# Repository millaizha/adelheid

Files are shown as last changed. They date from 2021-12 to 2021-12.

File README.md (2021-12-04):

# 𝕬𝖉𝖊𝖑𝖍𝖊𝖎𝖉

The Adelheid is a 75% Alice-like keyboard.  
It's a fork of FateNozomi's Arisu files: [Arisu PCB](https://github.com/FateNozomi/arisu-pcb) &amp; [Arisu case](https://github.com/FateNozomi/arisu-case)

This repo is a hand-wired version forked from [floookay's Adelheid](https://github.com/floookay/adelheid) with some changes.

This repository includes files for:

- a layered case &rarr; [README.md](./case/README.md)

## Changes in this fork

Here is a list of things I added in this fork in comparison to the original Adelheid:

- [x] replaced page up with a rotary encoder
- [x] lowered home, end, and page up keys (will change into media keys)
- [x] added win and right control keys
- [x] used pro micro as the controller
- [x] changed thickness of some acrylics

## Layout

A spaced 75% layout on top of the Alice/Arisu-layout.

[Keyboard-Layout-Editor](http://www.keyboard-layout-editor.com/#/gists/3d5f924367b3b31ac1beb2d660264759)
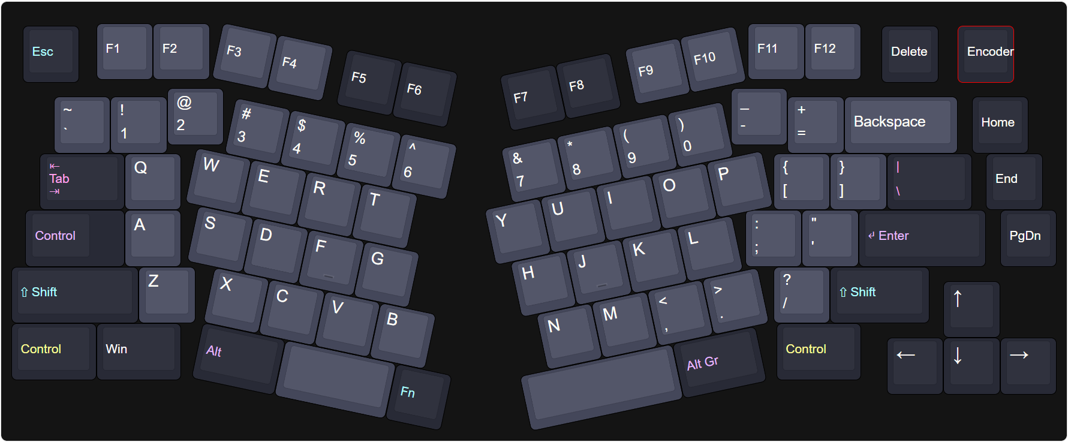
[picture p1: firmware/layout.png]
layout
 

## Firmware

See [firmware](https://github.com/millaizha/adelheid-hand-wire/tree/master/firmware)

## Images

For more images see [images.md](./IMAGES.md).

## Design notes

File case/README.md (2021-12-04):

# 𝕬𝖉𝖊𝖑𝖍𝖊𝖎𝖉 - Case

## Lasercutable Layered Case

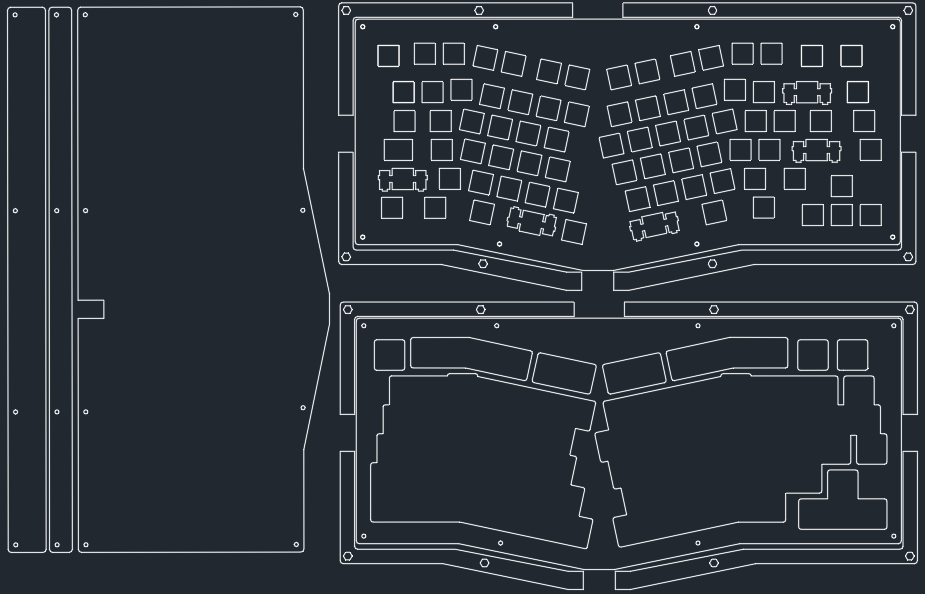
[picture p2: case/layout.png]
layout


final product (acrylic) to be put

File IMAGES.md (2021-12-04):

# 𝕬𝖉𝖊𝖑𝖍𝖊𝖎𝖉 hand-wired - Images

## Finished Keyboard

to be finished

## Case

CAD layout

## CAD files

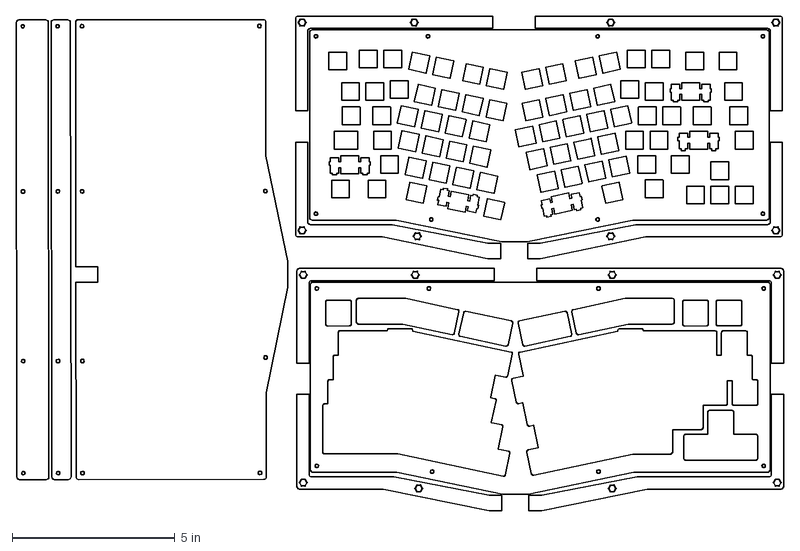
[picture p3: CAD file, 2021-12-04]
case/case.dxf
23.6 x 15.2 in

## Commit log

2020-04-16 added gerber files
    [adelheid-B_Cu.gbl, adelheid-B_Mask.gbs, adelheid-B_SilkS.gbo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]
2020-04-16 updated case files
    [adelheid_hipro_addon.dxf, adelheid_lopro.dxf, lasercut_adelheid_hipro_600x600.dxf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]
2020-04-27 added images of PCB and acrylic case layers
2020-04-27 updated pcb labels to be more consistent [v1.0.1]
    [adelheid-B_Cu.gbl, adelheid-B_Mask.gbs, adelheid-B_SilkS.gbo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]
2020-05-18 added footprints
    [arisu.kicad_pcb, arisu.sch, backlight.xlsx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]
2020-05-18 added column and row routing
    [arisu.kicad_pcb, matrix.sch]
2020-05-18 added matrix routing
    [arisu.kicad_pcb]
2020-05-18 finished pcb v2
    [arisu.kicad_pcb, arisu.sch, matrix.sch]
2020-05-18 restructured folder structure
    [adelheid.kicad_pcb, adelheid.sch, arisu.kicad_pcb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]
2020-05-20 updated readme + preparation for merge
    [adelheid-B_Cu.gbl, adelheid-B_Mask.gbs, adelheid-B_SilkS.gbo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]
2020-05-25 restructured case files, updated readmes
    [hipro_layers_addon.dxf, hipro_layers_addon.f3d, lopro_layers.dxf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]
2020-05-25 updated pcb readme
    [backlight.ods, backlight.xlsx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]
2020-05-27 made usb port cutout slightly larger
    [lopro_layers.dxf, lopro_layers.f3d]
2020-05-28 fixed revision number [Rev1.0]
    [adelheid.kicad_pcb, adelheid.sch]
2020-05-28 made usb port cutout larger in 600x600mm sheets
    [z_hipro_layers_600x600.dxf]
2020-06-01 altered hipro function row cutouts slightly
    these were slightly larger on the left half and have been resized so
    the cutouts should be more symmetrical now
    [hipro_layers_addon.dxf, hipro_layers_addon.f3d, z_hipro_layers_600x600.dxf]
2020-06-11 made pcb file compatible with stable KiCAD release
    compatible with KiCAD >5.1.6
    Previously pcbnew was only working with a testing build of KiCAD.
    [adelheid.kicad_pcb]
2020-07-11 switched backlight pin [Rev2.0]
    swapped col4 and led pin.
    Backlight is now on pin 31 (C6).
    In Rev1.0 the backlight started flickering because the MCU couldn't
    handle the load of the LEDs on pin 37. This should fix the issue.
    Thank you u/SryImBadAtNaming for finding out and notifying me!
    [adelheid.kicad_pcb, adelheid.sch, matrix.sch]
2020-07-14 added assembly parts list and standoffs to flat wr
2020-07-15 tested backlight support
    - tested backlight support for Rev2.0
    (200mA power draw with 99 LEDs at 1kΩ each
    - removed backlight support disclaimers
    - added tentative backlight picture
2020-09-14 removed scale
    [lopro_layers.dxf]
2021-03-20 added proto files for plate foam
    [foam.dxf, foam.f3d]
2021-12-04 Add case files
    [adelheid.csv, adelheid.kicad_pcb, adelheid.sch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]
